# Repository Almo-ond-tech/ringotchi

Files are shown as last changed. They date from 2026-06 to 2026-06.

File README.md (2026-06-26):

# ringotchi

ringotchi_zine3

# Description
A tamagotchi pet with an apple shape. The usb port plugs into the top of the apple to form the stem. The sprite for the pet is a cat with glasses to match the case. And it has a pet worm because it lives in an apple. I made this following the tutorial for hackclub fallout: [https://fallout.hackclub.com/docs/guided-projects/tamagotchi].
I like retro toys and I'm glad I get to make my own custom tamagotchi that I can personalise to do stuff. I'm thinking of adding extra stuff like a death screen and mini game but I'll just wait to build it in real life first. I also used this github as reference to program the jingles: https://github.com/FeFaxy/arduino_buzzer/blob/main/Twinkle_Twinkle_Little_Star.ino

<h2> Functions</h2>

</ul>
<h3> DISPLAY </h3>
<ul>
  <li> On the display there are three labels on the left aranged vertically and one label on the right. 
  <p> These labales correspond to the three switches on the left and the rotary encoder on the right. From top to down it goes: "[Feed]", "[Play]" and "[Sleep]". Then on the right: "[Bath]".  </p> </li>
  <li> At the bottom of the display there are the pet's current stats in long rectangular bars, which fill up in percentage according to the current value of said stat. It goes from top to bottom in the order: "HUN" (HUNGER), "HAP" (HAPPINESS), "ENG" (ENERGY), "HYG" (HYGIENE). </li>
  <li> The screen also features an age variable which keeps track of how many minutes your pet has been alive. </li>
  </ul>
  
<h3> BUTTONS </h3>
<ul>
  <li>The first button triggers the feed screen. The leds blinks and the buzzer rings in morse code to form the message: "EAT"
    <p>On this screen pressing the same button increases the hunger and energy stat and makes the pet more full. When the hunger stat reaches 100 the tamagotchi plays a little jingle</p> 
  </li>
  
  <li> The second button triggers the play screen. The leds blinks and the buzzer rings in morse code to form the message: "YAY"
     <p>On this screen pressing the same button increases the happiness stat but decreases the energy stat making the pet feel more tired. When the happiness reaches 100 the tamagotchi plays a little jingle</p> </li>

  <li> The third button triggers the sleep screen. The leds blinks and the buzzer rings in morse code to form the message: "ZZZ"
  <p>On this screen pressing the same button increases the energy stat and makes the pet feel more energetic. When the energy reaches 100 the tamagotchi plays a little jingle </p>
  </li>
  
  <li> The fourth button triggers the bath screen. The leds blinks and the buzzer rings in morse code to form the message: "EWW" 
    <p> On this screen you need to turn the rotary encoder a certain amount of time before the hygiene and energy stat increases. The screen displays how many turn are left to increment the stats by the set value. Each turn is equal to 5 rotations. Rotating the encoder a combined amount of 15 time to either the left and or right increases these stats imitaiting a scrubbing motion. Pressing the rotary encoder again returns back to the main screen. When the hygiene stat reaches 100 the tamagotchi plays a little jingle</p> </li>  
</ul>

<h3> MODES </h3>
<ul>
  <li> If the energy stat is below 40 the pet is tired and displays this image: <br>
    sprite_sleeping
 </li>
  <li> If the hygiene is below 30 the pet is dirty and displays this image: <br>
    sprite_dirty
 </li>
  <li> If the hunger and happiness stats are below 30 the pet is sad and displays this image: <br> 
    sprite_sad2
</li>
  <li> If the energy and happiness stats are above 60 the pet is happy and displays this image: <br> 
    sprite_happy
</li>  
<li>
  If the above conditions for the modes aren't met the pet has a neutral expression:  <br>
  sprite_neutral
</li>

### Disclaimer
Since I haven't build it in real life yet there are bound to be inaccuracies in the code or hardware. However I've tried my best to minimize those as much as possible. This image is thus just a vague rendition of what the screen could theoretically look like with the current code. <br>
main_screen_neutral

# Firmware setup
Make sure you have the neccesary libraries downloaded in Arduino ide. Select the board and configure the pins to match your pin numbers. At this step you can also customize the ringotchi. <br>
pin_libraries <br>
You can change the tunes that play by changing the notes in the (something_)jingle functions. <br>
change_jingle <br>
And also change the pattern of the morse code to be other messages in the morse(_something) variable at the top. <br>
change_morse <br>
Furthermore you can even customize your sprite by drawing it in [https://draw-to-bit.vercel.app/], copying the progmem(c) and replacing it in the code for PROGMEM pet(something). <br> 
change_sprite <br>

However make sure it is a 32 x 32 bit sprite as those are the dimensions used in this code. After customizing to your hearts desire upload the code to the Xiao ESPC3 and put together the casing.

# Casing
<a href='https://cad.onshape.com/documents/550f27ac1857586e625d99ee/w/67f007c674e2b675580248ba/e/c8e1a93a35cedfa3546ef407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'>
Onshape link </a> <br> Or copy paste in browser: [https://cad.onshape.com/documents/550f27ac1857586e625d99ee/w/67f007c674e2b675580248ba/e/c8e1a93a35cedfa3546ef407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] <br>

<h4>Step 1 :</h4> Building the casing is pretty straight forward.You print out the top and bottom case and gather the nessecary screws.
<h4> Step 1.5 (Optional): </h4> Paint and coat the case in your preffered colors. I recommend colors similar to the 3d model.
<h4> Step 2: </h4> Place the LiPo battery in the bottom compartment of the bottom case and connect it to the headers on the pcb.

case_noComponets

<h4> Step 3:</h4> Screw the pcb in place using two M3 screws on either sides of the pcb.
ringotchi_case_open

<h4>Step 4:</h4> Attach the top case by screwing it in place using 6 M3 screws.
ringotchi_case_side

Your Ringotchi is now fully assembled!
ringotchi_case_face

# PCB

<h2> Schematics</h2>
schematics_ringotchi

<h2> 3d Model PCB</h2>
pcb3d_front_ringotchi
pcb3d_back_ringotchi

<h2>PCB Routing </h2>
pcbRoute_ringotchi

# BOM (Bill of Materials)
[Ringotchi BOM - Sheet1.csv](https://github.com/user-attachments/files/29273973/Ringotchi.BOM.-.Sheet1.csv)

| Item | Description | Quantity | Unit Price ($) | Total Price($) | URL | Running Total With Tax ($) |
|---|---|---|---|---|---|---|
| M3 screws (50 pcs) | 3mm diameter counter sunk screws 8mm (6pcs) | 1 | 0.1296 | 6.48 | https://nl.aliexpress.com/item/1005008709978631.html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 | 6.48 |
| Lithium Polymer Battery 3.7 V 500 mAh 403048 Lipo Rechargeable Battery with Wired JST Connector | LiPo Battery | 1 | 11.6 | 11.6 | https://www.amazon.nl/gp/product/B095W6742D/ref=ox_sc_act_title_1?smid=ASLRAS85RTYN3&th=1 | 11.6 |
| 12*9.5mm Mini Active Piezo Buzzers (10 pcs) | 12x9.5 Buzzer 1pc | 1 | 0.694 | 6.94 | https://nl.aliexpress.com/item/1005010321957502.html?gatewayAdapt=usa2nld4itemAdapt | 1 |
| ESP32 C3 Development Board for Arduino Seeed Studio XIAO ESP32C3 | MCU | 1 | 6.26 | 6.26 | https://nl.aliexpress.com/item/1005006979844970.html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 | 6.26 |
| 0.96 inch OLED display module SSD1306 I2C SPI serial 128X64 LCD 4-pin white (Pin Headers soldered) | OLED Display | 1 | 2.5 | 2.5 | https://nl.aliexpress.com/item/1005006996785298.html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 | 2.5 |
| 5 pcs Encoder Switch EC11 With Push Button Switch 5-pin Plug-in 15mm Half Plump Shaft | Rotary Encoder with push button 1pc | 1 | 0.648 | 3.24 | https://nl.aliexpress.com/item/1005009120433387.html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 | 3.24 |
| Tactile Switch 6x6x10mm Center pin 2 pins (20 pcs) | 6mm Tactile switches 3pcs | 1 | 0.312 | 6.24 | https://nl.aliexpress.com/item/1005006120482626.html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 | 6.24 |
| 50 Pieces 2.54mm Single Row Pin Header Connector Strip 2Pin | 2pin Pin Headers | 1 | 0.107 | 5.35 | https://nl.aliexpress.com/item/4000988113226.html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 | 5.35 |
| 20 pieces metal film resistor 470K ohm | 470k ohm resistor | 1 | 0.4595 | 9.19 | https://nl.aliexpress.com/item/1005011814571889.html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 | 9.19 |
| 100 pcs 3mm LED Diode RGB | 2 LEDs | 1 | 0.0106 | 1.06 | https://nl.aliexpress.com/item/1005007989424003.html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 | 1.06 |
| **TOTAL** | | | | **58.86** | | |

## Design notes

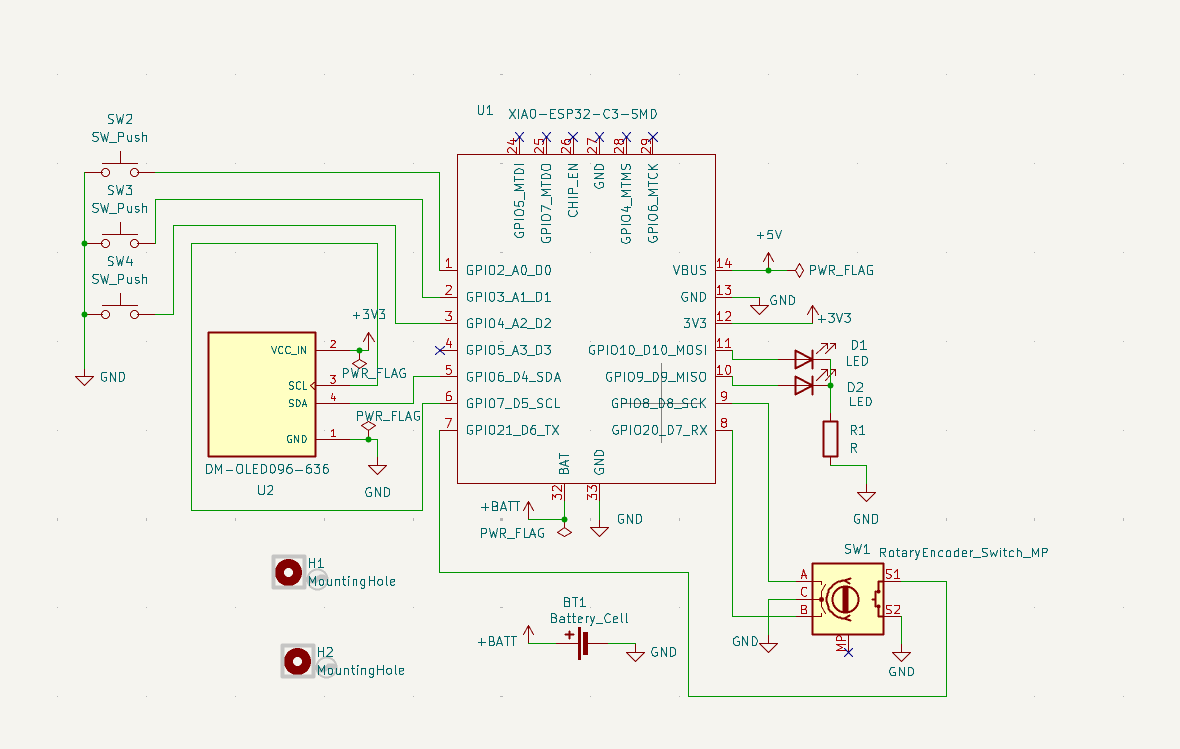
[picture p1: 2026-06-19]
docs/schematic_ringotchi.png

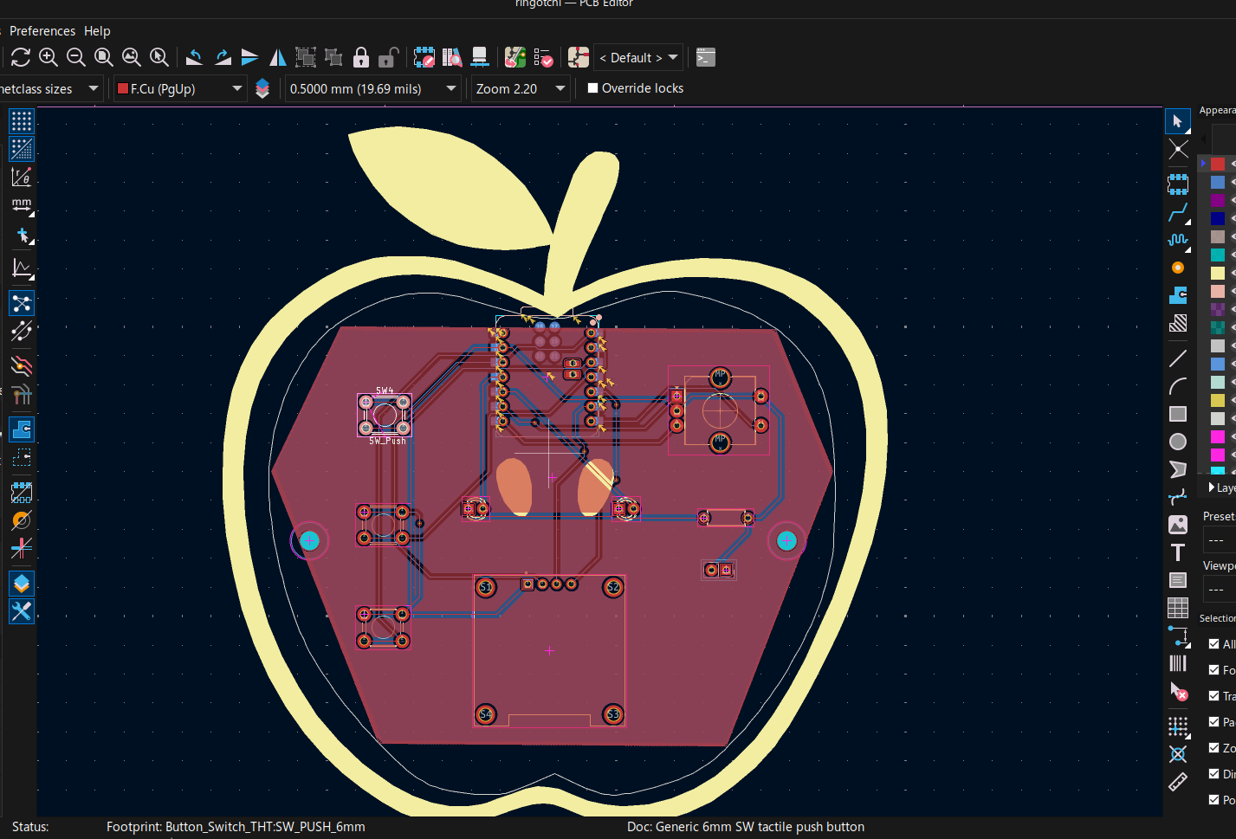
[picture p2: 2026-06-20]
ringotchi_pcb.png

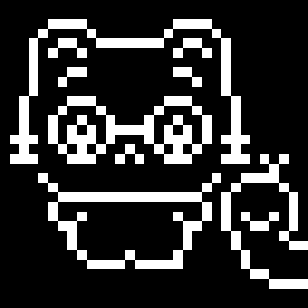
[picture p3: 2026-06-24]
docs/sprite_expressions/sprite_neutral.png

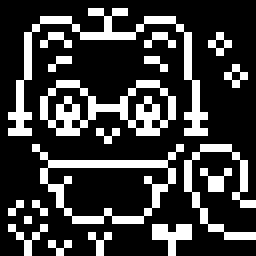
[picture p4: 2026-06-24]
docs/sprite_expressions/sprite_happy.png

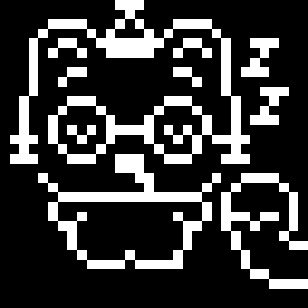
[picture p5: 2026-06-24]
docs/sprite_expressions/sprite_sleeping.png

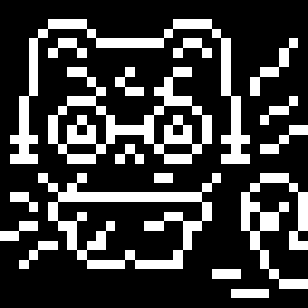
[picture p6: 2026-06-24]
docs/sprite_expressions/sprite_dirty.png

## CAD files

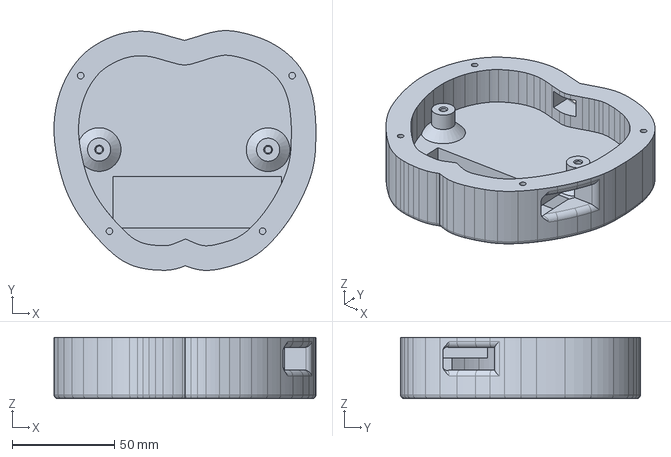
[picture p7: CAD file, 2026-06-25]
case_3d/Ringotchi case.step
127.9 x 117.0 x 30.0 mm

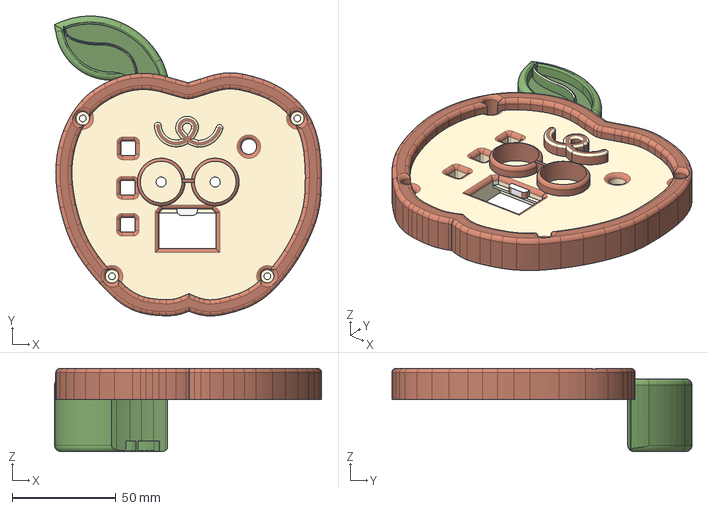
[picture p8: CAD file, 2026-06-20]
case_3d/ringotchi_cad-top case.step
128.5 x 144.4 x 40.0 mm

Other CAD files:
case_3d/ringotchi_cad-bottom case.step

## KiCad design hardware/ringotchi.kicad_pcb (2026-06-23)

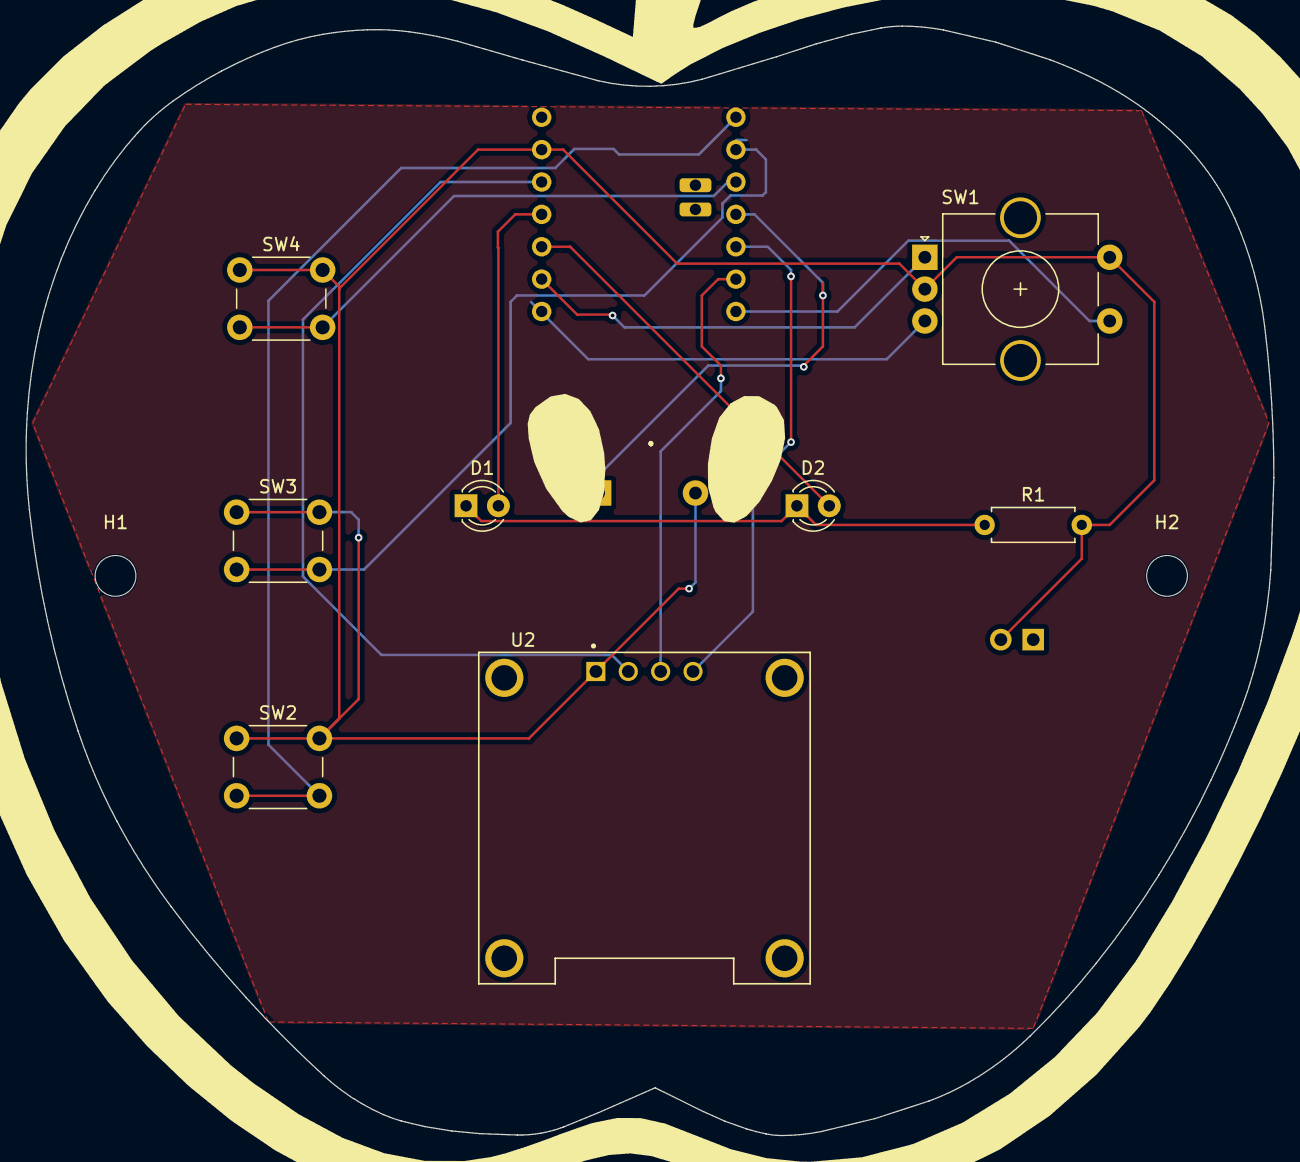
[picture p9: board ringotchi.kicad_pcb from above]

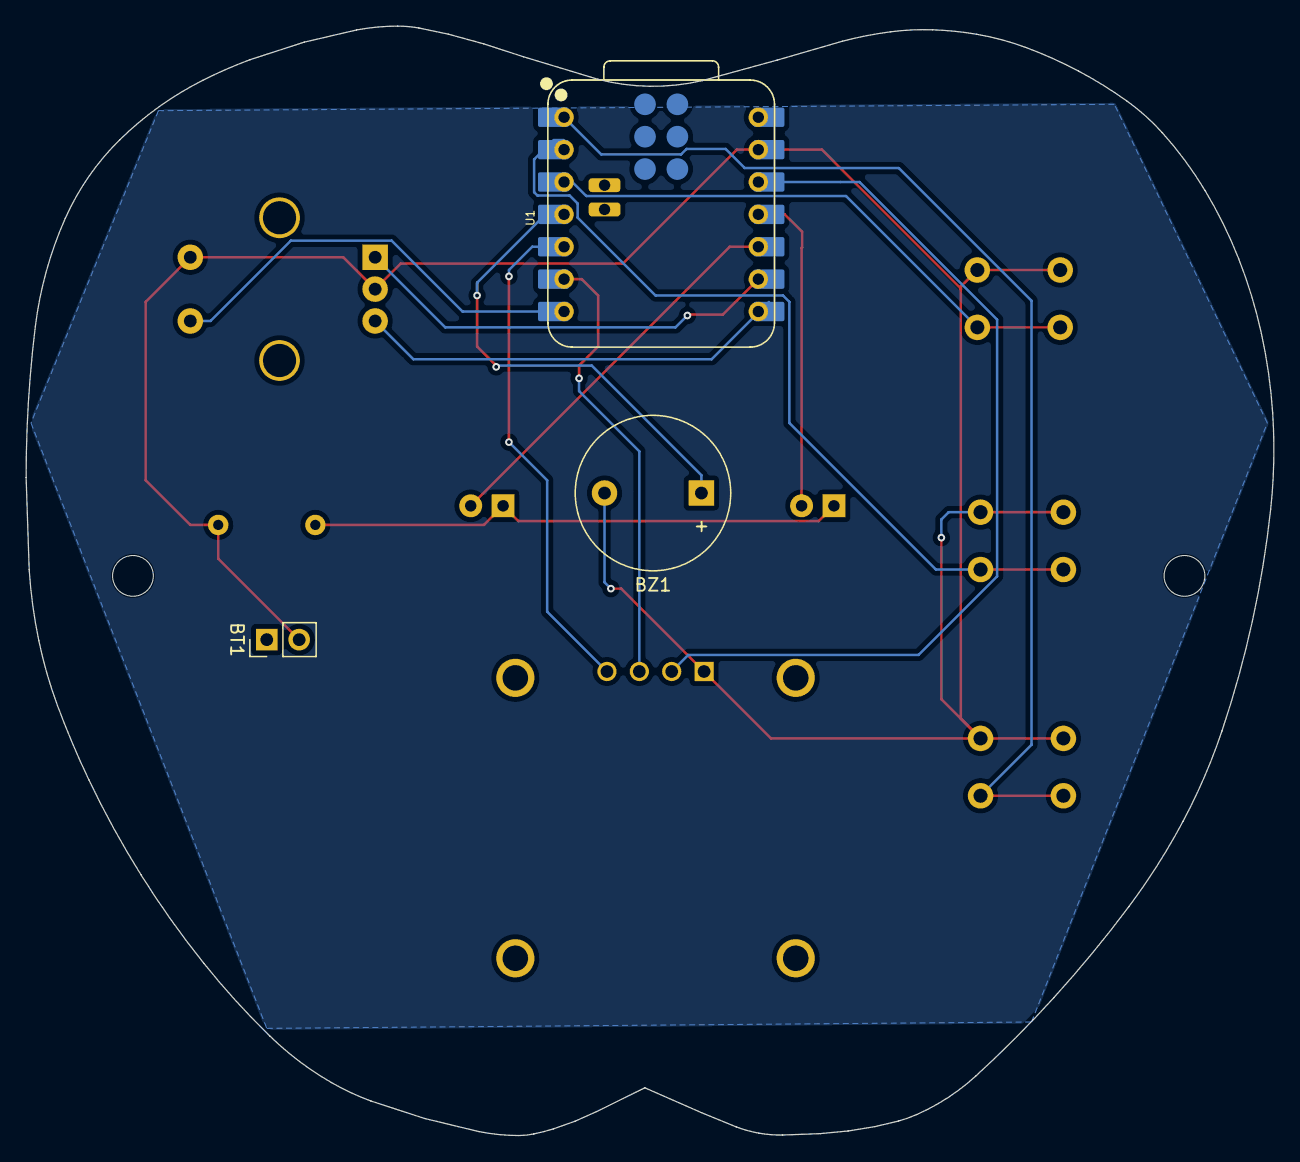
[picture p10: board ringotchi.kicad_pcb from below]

Board: 2 copper layers, 97.9 x 87.0 mm, 14 parts (3 on the bottom side), 14 nets.

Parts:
.: LOGO; apple_outline
BT1: Battery_Cell; PinHeader_1x02_P2.54mm_Vertical
BZ1: Buzzer; Buzzer_12x9.5RM7.6
D1, D2: LED; LED_D3.0mm
H1, H2: MountingHole; MountingHole_3.2mm_M3
R1: R; R_Axial_DIN0207_L6.3mm_D2.5mm_P7.62mm_Horizontal
SW1: RotaryEncoder_Switch_MP; RotaryEncoder_Alps_EC11E-Switch_Vertical_H20mm_CircularMoun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
SW2, SW3, SW4: SW_Push; SW_PUSH_6mm
U1: XIAO-ESP32-C3-SMD; XIAO-ESP32-C3-DIP-SMD
U2: DM-OLED096-636; MODULE_DM-OLED096-636

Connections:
+3V3: U1.12 (3V3), U2.2 (VCC_IN)
GND: BT1.2 (-), BZ1.2 (-), R1.2, SW1.C (GND), SW1.S2 (GND), SW2.1, SW3.1, SW4.1, U1.13 (GND), U2.1 (GND)
unnamed: BZ1.1 (+), U1.4 (GPIO5_A3_D3)
unnamed: D1.2 (A), U1.11 (GPIO10_D10_MOSI)
unnamed: D1.1 (K), D2.1 (K), R1.1
unnamed: D2.2 (A), U1.10 (GPIO9_D9_MISO)
unnamed: SW2.2, U1.1 (GPIO2_A0_D0)
unnamed: SW3.2, U1.2 (GPIO3_A1_D1)
unnamed: SW4.2, U1.3 (GPIO4_A2_D2)
unnamed: U1.5 (GPIO6_D4_SDA), U2.4 (SDA)
unnamed: U1.6 (GPIO7_D5_SCL), U2.3 (SCL)
unnamed: SW1.A, U1.9 (GPIO8_D8_SCK)
unnamed: SW1.B, U1.8 (GPIO20_D7_RX)
unnamed: SW1.S1, U1.7 (GPIO21_D6_TX)

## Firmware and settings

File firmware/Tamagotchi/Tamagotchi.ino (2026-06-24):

//Rotary Encoder (traced from schematics)
#define ROT_A 8 // Encoder A -> MCU Pin 9 -> GPIO8
#define ROT_B 20 // Encoder B -> MCU Pin 8 -> GPIO20
#define ROT_S1 21 // Encoder SW1 -> MCU Pin 7 -> GPIO21

//Buttons (traced from schematics)
#define BTN1 4 // SW4 -> MCU Pin 3 -> GPIO4 top
#define BTN2 3   // SW3 -> MCU Pin 2 -> GPIO3 middle
#define BTN3 2   // SW2 -> MCU Pin 1 -> GPIO2 bottom



// I2C OLED (traced from schematics)
#define SDA_PIN 6  // OLED SDA -> MCU Pin 5 -> GPIO6
#define SCL_PIN 7  // OLED SCL -> MCU Pin 6 -> GPIO7

// LEDS (traced from schematics)
#define LED_1 10 // D1 -> MCU 11 -> GPIO10
#define LED_2 9 // D2 -> MCU 10 -> GPIO9

// Buzzer (traced from schematic)
#define BUZZER_PIN 5   // Buzzer signal → MCU Pin 4 → GPIO5

#include <Wire.h>
#include <Adafruit_GFX.h>
#include <Adafruit_SSD1306.h>

#define SCREEN_WIDTH 128
#define SCREEN_HEIGHT 64
#define OLED_RESET -1

Adafruit_SSD1306 display(SCREEN_WIDTH, SCREEN_HEIGHT, &Wire, OLED_RESET);

// Morse patterns for each status alert
const char* morse_hungry = ". .- -"; // EAT
const char* morse_play = "-.-- .- -.--";  // YAY
const char* morse_dirty = ". .-- .--";    // EWW
const char* morse_sleep = "--.. --.. --.."; //ZZZ

// State machine tracker variables
const char* currentPattern = nullptr;
int patternIndex = 0;
unsigned long morseMillis = 0;
bool ledIsOn = false;

//Screen Bath variables
volatile int CW = 0;
volatile int CCW = 0;
volatile int turnCounter = 0;
volatile unsigned long lastRun = 0;
int totalRotation;
int turnsLeft;

// Notes as frequencies in Hertz (A4=440)
// "NOTE_" prefix avoids conflict with Arduino's analog pin names (A0–A5)
const int NOTE_C4 = 262;
const int NOTE_D4 = 294;
const int NOTE_E4 = 330;
const int NOTE_F4 = 349;
const int NOTE_G4 = 392;
const int NOTE_A4 = 440;
const int NOTE_B4 = 494;
const int NOTE_C5 = 523;
const int REST    = 0;   // silence

// --- Timing control ---
const int BPM = 120;               // beats per minute
const int QUARTER = 60000 / BPM;   // 1 beat = 60000ms / BPM
bool jinglePlayed = false; // Tracks if the 100% sound alert has already fired


struct Pet {
  int hunger;       // 0 to 100 (0 = starving, 100 = full)
  int happiness;    // 0 to 100 (0 = miserable, 100 = ecstatic)
  int energy;       // 0 to 100 (0 = exhausted, 100 = fully rested)
  int hygiene;      // 0 to 100 (0 = filthy, 100 = sparkling clean)
  float age; // total seconds the pet has been alive
};

Pet pet;

enum Screen {
  SCREEN_MAIN,
  SCREEN_FEED,
  SCREEN_PLAY,
  SCREEN_SLEEP,
  SCREEN_BATH
};

Screen currentScreen = SCREEN_MAIN;


void setup() {

  pinMode(BTN1, INPUT_PULLUP);
  pinMode(BTN2, INPUT_PULLUP);
  pinMode(BTN3, INPUT_PULLUP);
  pinMode(ROT_S1, INPUT_PULLUP);
  pinMode(ROT_A, INPUT_PULLUP); 
  pinMode(ROT_B, INPUT_PULLUP);
  pinMode(LED_1, OUTPUT);
  pinMode(LED_2, OUTPUT);
  pinMode(BUZZER_PIN, OUTPUT);

  
  attachInterrupt(digitaPinToInterrupt(ROT_A), updateRotation(), FALLING);

  display.begin(SSD1306_SWITCHCAPVCC, 0x3C);
  display.clearDisplay();
  display.setTextSize(1);
  display.setTextColor(SSD1306_WHITE);
  display.setCursor(0, 0);
  display.println("Tamagotchi Init...");
  display.display();
  delay(1000);

  pet.hunger = 70;
  pet.happiness = 70;
  pet.energy = 70;
  pet.hygiene = 70;
  pet.age = 0;
}

void loop() {
  checkButtons();       // 1. Read input
  updatePet();          // 2. Update state over time
  handleScreenLogic();  // 3. Process actions
  processMorseEngine();
  render();             // 4. Display results
  delay(100);           // 5. Short pause

}  
void processMorseEngine() {
  if (currentPattern == nullptr) return; // No alert running

  char currentSymbol = currentPattern[patternIndex];

  // If we reach the end of the string, stop the pattern
  if (currentSymbol == '\0') {
    digitalWrite(LED_1, LOW);
    digitalWrite(LED_2, LOW);
    currentPattern = nullptr; // Turn engine off
    return;
  }

  unsigned long currentMillis = millis();

  if (!ledIsOn) {
    // LED IS OFF: Determine how long it should turn ON for
    if (currentSymbol == '.' || currentSymbol == '-') {
    digitalWrite(LED_1, HIGH);
    digitalWrite(LED_2, HIGH);
    ledIsOn = true;
    morseMillis = currentMillis;

  
    unsigned long targetDuration = (currentSymbol == '.') ? 50 : 300;
    tone(BUZZER_PIN, 1000, targetDuration);
  } 
    else if (currentSymbol == ' ') {
      // Space! Keep LEDs off for a longer inter-word pause (400ms)
      if (currentMillis - morseMillis >= 400) {
        patternIndex++; // Move to next character
        morseMillis = currentMillis;
      }
    }
  } 
  else {
    // LED IS ON: Wait for the blink time to expire, then turn OFF
    unsigned long targetDuration = (currentSymbol == '.') ? 50 : 300;

    if (currentMillis - morseMillis >= targetDuration) {
      digitalWrite(LED_1, LOW);
      digitalWrite(LED_2, LOW);
      ledIsOn = false;
      
      // Standard small gap between symbols inside the same phrase (100ms) 
      //makes the targetDuration a negative number so that there is a pause between symbools
      morseMillis = currentMillis + 100; 
      patternIndex++; // Step to the next dot or dash
    }
  }
}

void triggerAlert(const char* pattern) {
  currentPattern = pattern;
  patternIndex = 0;
  morseMillis = millis();
  ledIsOn = false;
}

unsigned long lastUpdate = 0; // check how mauch time has passed

void updatePet() {
  if (millis() - lastUpdate > 15000) {  // every 15 seconds
    pet.hunger -= 2;
    pet.happiness -= 2;
    pet.energy -= 2;
    pet.hygiene -= 2;

    if (pet.hunger < 0) pet.hunger = 0;
    if (pet.happiness < 0) pet.happiness = 0;
    if (pet.energy < 0) pet.energy = 0;
    if (pet.hygiene < 0) pet.hygiene = 0;

    pet.age += 0.25;
    lastUpdate = millis();
  }
}

unsigned long lastButtonPress = 0;

void checkButtons() {
  if (millis() - lastButtonPress < 200) return;  // debounce: ignore presses within 200ms
  
  if (currentPattern != nullptr) {
    currentPattern = nullptr;
    digitalWrite(LED_1, LOW);
    digitalWrite(LED_2, LOW); 
    noTone(BUZZER_PIN);
    
  }

  if (digitalRead(BTN1) == LOW) {
    currentScreen = SCREEN_FEED;
    triggerAlert(morse_hungry);
    lastButtonPress = millis();
  }
  else if (digitalRead(BTN2) == LOW) {
    currentScreen = SCREEN_PLAY;
    tiggerAlert(morse_play);
    lastButtonPress = millis();
  }
  else if (digitalRead(BTN3) == LOW) {
    currentScreen = SCREEN_SLEEP;
    tiggerAlert(morse_sleep);
    lastButtonPress = millis();
  }
  else if (digitalRead(ROT_S1) == LOW) {
    currentScreen = SCREEN_BATH;
    tiggerAlert(morse_dirty);
    lastButtonPress = millis();
  }

}


void handleScreenLogic() {
  switch(currentScreen) {

    case SCREEN_FEED:
      pet.hunger += 8;
      pet.energy += 5;
      if (pet.hunger > 100) pet.hunger = 100;
      if (pet.energy > 100) pet.energy = 100;
      if (pet.hunger >= 100 && !jinglePlayed) {
        full_jingle();
        jinglePlayed = true;
      }
      currentScreen = SCREEN_MAIN;
      break;

    case SCREEN_PLAY:
      pet.happiness += 8;
      pet.energy -= 5;
      if (pet.happiness > 100) pet.happiness = 100;
      if (pet.energy < 0) pet.energy = 0;
      if (pet.happiness >= 100 && !jinglePlayed){
        happy_jingle();
        jinglePlayed = true;
      }
      currentScreen = SCREEN_MAIN;
      break;

    case SCREEN_SLEEP:
      pet.energy += 10;
      if (pet.energy > 100) pet.energy = 100;
      if (pet.energy >= 100 && !jinglePlayed){
        energy_jingle();
        jinglePlayed = true;
      }
      currentScreen = SCREEN_MAIN;
      break;

    case SCREEN_BATH:

     // press takes you to screen bath
     // turning knob --> turnCounter = 5 then hygiene and energy increase

      checkRotation();
      displayTurns();

      if (pet.hygiene > 100) pet.hygiene = 100;
      if (pet.energy < 0) pet.energy = 0;

      if (digitalRead(ROT_S1) == LOW) {
        currentScreen = SCREEN_MAIN; //if button pressed again THEN break TO MAIN SCREEN 
        delay(200);
      }
      if (pet.hygiene >= 100 && !jinglePlayed){
        clean_jingle();
        jinglePlayed = true;
      }
      break;

    case SCREEN_MAIN:
      jinglePlayed = false;
      break;  // do nothing, just display stats
  }
}


void updateRotation(){

  unsigned long currentMillis = millis();

  if (currentMillis - lastRun > 5){
   //make sure atleast 5ms passed since rotation

   lastRun = currentMills;

    if (digitalPinRead(ROT_B) == HIGH){
      Serial.print("Clockwise");
      CW += 1;
    } else if (digitalPinRead(ROT_B) == LOW){
      Serial.print("Counter Clockwise");
      CCW += 1;
    }
  }
}

void checkRotation(){

  totalRotations = CW + CCW;

  if (totalRotation >= 5){

    turnCounter += 1;

    CW = 0;
    CCW = 0;

    if (turnCounter >= 3) {

      pet.hygiene += 10;
      pet.energy -= 5;

      turnCounter = 0;
    }
    
  }
  
}

void displayTurns(){

  turnsLeft = 3 - turnCounter;
  
  display.setCursor(92, 22); 
  display.print("Scrubs"); 

  display.setCursor(92, 31);
  display.print("Left: ");
  display.print(turnsLeft);


}

// --- Helper function to play a note ---
void playTone(int frequency, int duration) {
  if (frequency == REST) {
    delay(duration); // silence
  } else {
    // tone() rapidly switches the pin between HIGH and LOW at 'frequency' Hz
    tone(BUZZER_PIN, frequency, duration);
    delay(duration * 1.3); // short gap between notes
  }
}

void happy_jingle (){

  playTone(NOTE_G4, QUARTER);
  playTone(NOTE_A4, QUARTER);
  playTone(NOTE_A4, QUARTER);
  playTone(NOTE_B4, QUARTER);

}

void full_jingle (){

  playTone(NOTE_F4, QUARTER);
  playTone(NOTE_B4, QUARTER);
  playTone(NOTE_B4, QUARTER);
  playTone(NOTE_G4, QUARTER);
  playTone(NOTE_A4, QUARTER);

}

void energy_jingle (){

  playTone(NOTE_F4, QUARTER);
  playTone(NOTE_A4, QUARTER);
  playTone(NOTE_C4, QUARTER);
  playTone(NOTE_C4, QUARTER);


}

void clean_jingle(){

  playTone(NOTE_G4, QUARTER);
  playTone(NOTE_G4, QUARTER);
  playTone(NOTE_D4, QUARTER);
  playTone(NOTE_B4, QUARTER);

}

void render() {

  display.clearDisplay();

  // Choose the right sprite based on pet stats
  const unsigned char* sprite;
  if (pet.energy < 40) {
    sprite = petSleep;
  } else if (pet.hygiene < 30) {
    sprite = petDirty;
  } else if (pet.hunger < 30 || pet.happiness < 30) {
    sprite = petSad;
  } else if (pet.happiness > 60 && pet.energy > 60) {
    sprite = petHappy;
  } else {
    sprite = petNeutral;
  }

  if (currentScreen == SCREEN_BATH){

    displayTurns();

  }

  // Draw the pet sprite (centered horizontally, near the top)
  display.drawBitmap(56, 2, sprite, 32, 32, SSD1306_WHITE);

  // Draw stat bars below the pet
  display.setTextSize(1);

  display.setCursor(0, 39);
  display.print("HUN ");
  drawBar(24, 41, pet.hunger);

  display.setCursor(0, 46);
  display.print("HAP ");
  drawBar(24, 48, pet.happiness);

  display.setCursor(0, 53);
  display.print("ENG ");
  drawBar(24, 55, pet.energy);

  display.setCursor(0, 60);
  display.print("HYG ");
  drawBar(24, 62, pet.hygiene);

  // Draw age
  display.setCursor(95, 2);
  display.print("Age: ");
  display.print(pet.age);

  // Button labels at the sides
  display.setCursor(2, 2);
  display.println("[Feed]");

  display.setCursor(2, 11);
  display.println("[Play]");

  display.setCursor(2, 20);
  display.println("[Sleep]");

  display.setCursor(92, 12);
  display.println("[Bath]");

  display.display();
}

// Draws a stat bar: empty rectangle with a filled portion based on value (0 to 100)
void drawBar(int x, int y, int value) {
  int barWidth = 90;
  int barHeight = 3;
  int fillWidth = map(value, 0, 100, 0, barWidth);

  display.drawRect(x, y, barWidth, barHeight, SSD1306_WHITE);       // outline
  display.fillRect(x, y, fillWidth, barHeight, SSD1306_WHITE);      // filled portion
}

void triggerAlert(const char* pattern) {
  currentPattern = pattern;
  patternIndex = 0;
  morseMillis = millis();
  ledIsOn = false;
}


const unsigned char PROGMEM petHappy[] = {
  0b00000000, 0b00000000, 0b00000000, 0b00000000,
  0b00000000, 0b00011011, 0b00000000, 0b00000000,
  0b00000111, 0b10000100, 0b00111100, 0b00000000,
  0b00001000, 0b01000100, 0b01000010, 0b00000000,
  0b00010011, 0b00111111, 0b10011001, 0b00010000,
  0b00010100, 0b10000000, 0b00100101, 0b00101000,
  0b00010000, 0b00000000, 0b00000001, 0b00010000,
  0b00010001, 0b10000000, 0b00110001, 0b00000000,
  0b00010010, 0b00000000, 0b00001001, 0b00000100,
  0b00010000, 0b00000000, 0b00000001, 0b00001010,
  0b00100001, 0b11000000, 0b01110000, 0b10000100,
  0b00100010, 0b00100000, 0b10001000, 0b10000000,
  0b00100100, 0b10010001, 0b00100100, 0b10000000,
  0b00100101, 0b01011111, 0b01010100, 0b10000000,
  0b01110101, 0b11010001, 0b01110101, 0b11000000,
  0b00100010, 0b10100000, 0b10101000, 0b10000000,
  0b01110001, 0b11001010, 0b01110001, 0b11000000,
  0b00000000, 0b00000100, 0b00000000, 0b00000000,
  0b00001000, 0b00000000, 0b00000010, 0b01111000,
  0b00000100, 0b00000000, 0b00000100, 0b10000100,
  0b00000011, 0b11111111, 0b11111001, 0b00000010,
  0b00000100, 0b00000000, 0b00000101, 0b01001010,
  0b00000100, 0b10000000, 0b00100101, 0b00110010,
  0b00000011, 0b00000000, 0b00011001, 0b00110010,
  0b00000001, 0b00000000, 0b00010000, 0b10000100,
  0b00101001, 0b00000000, 0b00010000, 0b10000011,
  0b01000100, 0b10000100, 0b00100000, 0b01000000,
  0b00010000, 0b01111011, 0b11000000, 0b01000000,
  0b01000100, 0b00000000, 0b00011011, 0b00110000,
  0b00101000, 0b00010100, 0b00011111, 0b00001111,
  0b00010010, 0b10001000, 0b00000100, 0b00000000,
  0b00010001, 0b00001000, 0b00000100, 0b00000000
};

const unsigned char PROGMEM petsad[] = {
  0b00000000, 0b00000000, 0b00000000, 0b00000000,
  0b00000000, 0b00001010, 0b00000000, 0b00000000,
  0b00000111, 0b10010101, 0b00111100, 0b00000000,
  0b00001000, 0b01000100, 0b01000010, 0b00000000,
  0b00010011, 0b00111111, 0b10011001, 0b00000000,
  0b00010100, 0b10000000, 0b00100101, 0b00000000,
  0b00010000, 0b00100000, 0b10000001, 0b00101010,
  0b00010000, 0b11000000, 0b01100001, 0b00101010,
  0b00010001, 0b00000000, 0b00010001, 0b00101010,
  0b00010000, 0b00000000, 0b00000001, 0b00001010,
  0b00100001, 0b11000000, 0b01110000, 0b10000010,
  0b00100010, 0b00100000, 0b10001000, 0b10000010, 
  0b00100100, 0b10010001, 0b00100100, 0b10000000,
  0b00100101, 0b01011111, 0b01010100, 0b10000000,
  0b01110101, 0b11010001, 0b01110101, 0b11000000,
  0b00100010, 0b10100100, 0b10101000, 0b10000000,
  0b01110001, 0b11001010, 0b01110001, 0b11000000,
  0b00000000, 0b10000000, 0b00100000, 0b00000000,
  0b00001000, 0b00000000, 0b00100010, 0b01111000,
  0b00000100, 0b00000000, 0b00000100, 0b10000100,
  0b00000011, 0b11111111, 0b11111001, 0b00000010,
  0b00000100, 0b00000000, 0b00000101, 0b00000010,
  0b00000100, 0b10000000, 0b00100101, 0b01001010,
  0b00000011, 0b00000000, 0b00011001, 0b00110010,
  0b00000001, 0b00000000, 0b00010000, 0b10000100,
  0b00000001, 0b00000000, 0b00010000, 0b10000011,
  0b00000000, 0b10000100, 0b00100000, 0b01000000,
  0b00000000, 0b01111011, 0b11000000, 0b01000000,
  0b00000000, 0b00000000, 0b00000000, 0b00110000,
  0b00000000, 0b00000000, 0b00000000, 0b00001111,
  0b00000000, 0b00000000, 0b00000000, 0b00000000,
  0b00000000, 0b00000000, 0b00000000, 0b00000000
};

const unsigned char PROGMEM petSleep[] = {
  0b00000000, 0b00001110, 0b00000000, 0b00000000,
  0b00000000, 0b00000100, 0b00000000, 0b00000000,
  0b00000111, 0b10001010, 0b00111100, 0b00000000,
  0b00001000, 0b01010001, 0b01000010, 0b00000000,
  0b00010011, 0b00111111, 0b10011001, 0b00111000,
  0b00010100, 0b10011111, 0b00100101, 0b00010000,
  0b00010000, 0b00000000, 0b00000001, 0b00100000,
  0b00010001, 0b10000000, 0b00110001, 0b01110000,
  0b00010010, 0b00000000, 0b00001001, 0b00000000,
  0b00010000, 0b00000000, 0b00000001, 0b00011100,
  0b00100001, 0b11000000, 0b01110000, 0b10001000,
  0b00100010, 0b00100000, 0b10001000, 0b10010000,
  0b00100100, 0b00010001, 0b00000100, 0b10111000,
  0b00100101, 0b01011111, 0b01010100, 0b10000000,
  0b01110100, 0b10010001, 0b00100101, 0b11000000,
  0b00100010, 0b00100000, 0b10001000, 0b10000000,
  0b01110001, 0b11001110, 0b01110001, 0b11000000,
  0b00000000, 0b00001110, 0b00000000, 0b00000000,
  0b00001000, 0b00000011, 0b00000010, 0b01111000,
  0b00000100, 0b00000001, 0b00000100, 0b10000100,
  0b00000011, 0b11111111, 0b11111001, 0b00000010,
  0b00000100, 0b00000000, 0b00000101, 0b00000010,
  0b00000100, 0b10000000, 0b00100101, 0b11011010,
  0b00000011, 0b00000000, 0b00011001, 0b00100010,
  0b00000001, 0b00000000, 0b00010000, 0b10000100,
  0b00000001, 0b00000000, 0b00010000, 0b10000011,
  0b00000000, 0b10000100, 0b00100000, 0b01000000,
  0b00000000, 0b01111011, 0b11000000, 0b01000000,
  0b00000000, 0b00000000, 0b00000000, 0b00110000,
  0b00000000, 0b00000000, 0b00000000, 0b00001111,
  0b00000000, 0b00000000, 0b00000000, 0b00000000,
  0b00000000, 0b00000000, 0b00000000, 0b00000000
};

const unsigned char PROGMEM petDirty[] = {
  0b00000000, 0b00000000, 0b00000000, 0b00000000,
  0b00000000, 0b00000000, 0b00000000, 0b00000000,
  0b00000111, 0b10000000, 0b00111100, 0b00000000,
  0b00001000, 0b01000000, 0b01000010, 0b00000000,
  0b00010011, 0b00111111, 0b10011001, 0b00000010,
  0b00010100, 0b10000000, 0b00100101, 0b00000100,
  0b00010000, 0b00000000, 0b00000001, 0b00000100,
  0b00010001, 0b10000100, 0b00110001, 0b00011000,
  0b00010000, 0b01001000, 0b01000001, 0b00100000,
  0b00010000, 0b00100110, 0b10000001, 0b00100000,
  0b00100001, 0b11000000, 0b01110000, 0b10000010,
  0b00100010, 0b00100000, 0b10001000, 0b10001100,
  0b00100100, 0b10010001, 0b00100100, 0b10010000,
  0b00100101, 0b01011111, 0b01010100, 0b10000011,
  0b01110101, 0b11010001, 0b01110101, 0b11000100,
  0b00100010, 0b00100100, 0b10001000, 0b10011000,
  0b01110001, 0b11001010, 0b01110001, 0b11000000,
  0b00000000, 0b00000000, 0b00000000, 0b00000000,
  0b00001000, 0b10000000, 0b11000010, 0b00011100,
  0b00000101, 0b00000000, 0b00000100, 0b00100010,
  0b01100011, 0b11111111, 0b11111000, 0b01000001,
  0b00010100, 0b00000000, 0b00000100, 0b01100101,
  0b00000100, 0b10000000, 0b01100100, 0b01011001,
  0b00110011, 0b00010001, 0b10011000, 0b01011001,
  0b11000001, 0b00100000, 0b00010000, 0b00100010,
  0b00001101, 0b01100000, 0b00010000, 0b00100011,
  0b00010000, 0b10000100, 0b00100000, 0b00010000,
  0b00100000, 0b01111011, 0b11000000, 0b00010000,
  0b00000000, 0b00000000, 0b00000011, 0b10001000,
  0b00000000, 0b00000000, 0b00000000, 0b00000111,
  0b00000000, 0b00000000, 0b00000000, 0b11110000,
  0b00000000, 0b00000000, 0b00000000, 0b00000000
};

const unsigned char PROGMEM petNeutral[] = {
  0b00000000, 0b00000000, 0b00000000, 0b00000000,
  0b00000000, 0b00000000, 0b00000000, 0b00000000,
  0b00000111, 0b10000000, 0b00111100, 0b00000000,
  0b00001000, 0b01000000, 0b01000010, 0b00000000,
  0b00010011, 0b00111111, 0b10011001, 0b00000000,
  0b00010100, 0b10000000, 0b00100101, 0b00000000,
  0b00010000, 0b00000000, 0b00000001, 0b00000000,
  0b00010001, 0b10000000, 0b00110001, 0b00000000,
  0b00010010, 0b00000000, 0b00001001, 0b00000000,
  0b00010000, 0b00000000, 0b00000001, 0b00000000,
  0b00100001, 0b11000000, 0b01110000, 0b10000000,
  0b00100010, 0b00100000, 0b10001000, 0b10000000,
  0b00100100, 0b10010001, 0b00100100, 0b10000000,
  0b00100101, 0b01011111, 0b01010100, 0b10000000,
  0b01110101, 0b11010001, 0b01110101, 0b11000000,
  0b00100010, 0b10100100, 0b10101000, 0b10000000,
  0b01110001, 0b11001010, 0b01110001, 0b11010100,
  0b00000000, 0b00000000, 0b00000000, 0b00001000,
  0b00001000, 0b00000000, 0b00000010, 0b01111000,
  0b00000100, 0b00000000, 0b00000100, 0b10000100,
  0b00000011, 0b11111111, 0b11111001, 0b00000010,
  0b00000100, 0b00000000, 0b00000101, 0b00000010,
  0b00000100, 0b10000000, 0b00100101, 0b01001010,
  0b00000011, 0b00000000, 0b00011001, 0b00110010,
  0b00000001, 0b00000000, 0b00010000, 0b10000100,
  0b00000001, 0b00000000, 0b00010000, 0b10000011,
  0b00000000, 0b10000100, 0b00100000, 0b01000000,
  0b00000000, 0b01111011, 0b11000000, 0b01000000,
  0b00000000, 0b00000000, 0b00000000, 0b00110000,
  0b00000000, 0b00000000, 0b00000000, 0b00001111,
  0b00000000, 0b00000000, 0b00000000, 0b00000000,
  0b00000000, 0b00000000, 0b00000000, 0b00000000
};

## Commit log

2026-06-19 Add images to README for schematic and PCB
    Added images to README for better visualization.
2026-06-19 Add 3D PCB images to README
    Added additional images of the PCB in 3D view.
2026-06-20 Add casing and PCB images to README
2026-06-20 Rename ringotchi_cad-bottom case.step to case_3d/ringotchi_cad-bottom case.step
    [ringotchi_cad-bottom case.step]
2026-06-20 Rename ringotchi_cad-top case.step to case_3d/ringotchi_cad-top case.step
    [ringotchi_cad-top case.step]
2026-06-24 Add new PCB 3D model file
    [pcb_3dmodel.step]
2026-06-24 Rename Ringotchi BOM - Sheet1.csv to docs/Ringotchi BOM - Sheet1.csv
    [Ringotchi BOM - Sheet1.csv]
2026-06-24 Enhance README with project details and instructions
    Added detailed project description, functions, buttons, modes, and assembly instructions for the Ringotchi.
